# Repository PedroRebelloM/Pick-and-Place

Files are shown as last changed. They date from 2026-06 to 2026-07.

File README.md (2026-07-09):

# Máquina CNC Pick-and-Place (Separação Automática)

Uma máquina CNC (Controle Numérico Computadorizado) projetada para separar e organizar automaticamente parafusos e porcas de acordo com seus tipos, utilizando visão computacional e precisão robótica.

## 🎯 Visão Geral do Projeto

Este projeto visa desenvolver um sistema automatizado de *pick-and-place* (pegar e colocar) que:
- **Identifica** diferentes tipos de parafusos e porcas usando visão computacional.
- **Classifica** os fixadores por suas características (tamanho, tipo, formato).
- **Separa e Organiza** os componentes em recipientes ou compartimentos designados.
- **Otimiza** os movimentos de deslocamento e captura (eixos X e Y) para maior velocidade e precisão.

## 📋 Funcionalidades (Roadmap)

- [ ] Sistema de visão computacional para detecção e classificação de peças.
- [ ] Atuador magnético (Eletroímã controlado por Servo Motor) para captura precisa.
- [ ] Sistema de controle de movimento CNC (Arduino + CNC Shield).
- [ ] Separação e organização em tempo real.
- [ ] Regras de classificação personalizáveis.
- [ ] Interface de usuário (Dashboard) para monitoramento de estatísticas.

## 🏗️ Arquitetura do Sistema

### Componentes de Hardware
- Sistema de Movimento CNC:
  - 1 Arduino Uno
  - 1 CNC Shield V3.0
  - 3 Módulos de Driver A4988
  - 3 Motores NEMA 17
- Ferramenta de Captura:
  - Eletroímã
  - Servo Motor MG90S
  - Módulo Relé 
- Câmera para visão computacional.
- Recipientes de separação para os componentes classificados.

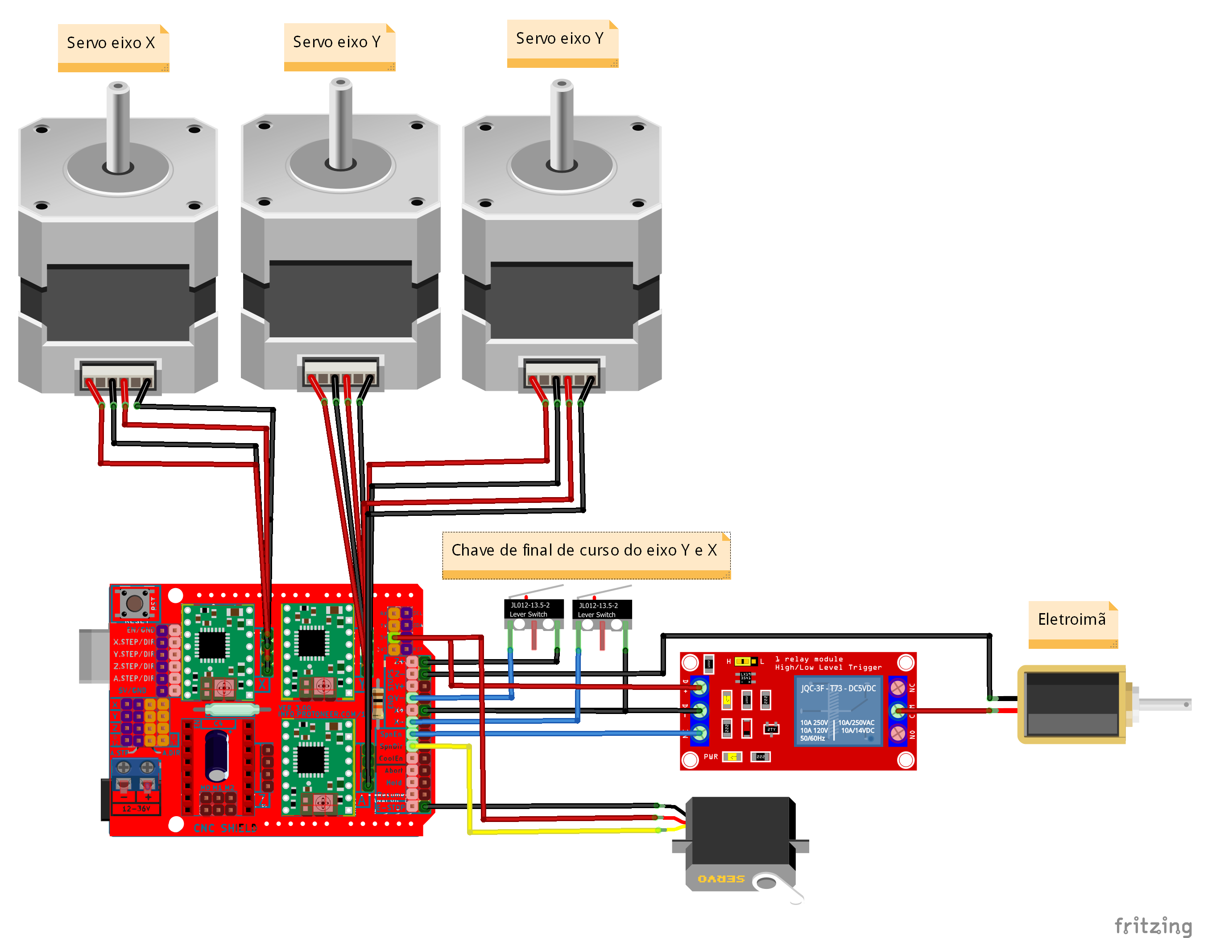
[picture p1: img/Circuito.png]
Circuito CNC


### Componentes de Software
- **Visão Computacional:** Algoritmo de detecção e classificação (Raspberry Pi / PC com Python e OpenCV).
- **Firmware de Controle de Movimento:** Lógica em C++ utilizando a [Biblioteca AccelStepper](https://github.com/adafruit/AccelStepper/blob/master/AccelStepper.h#L154) (Arduino).
- **Comunicação e Backend:** Processamento de dados em tempo real via porta Serial e servidor web (Python + flet).
- **Interface/Dashboard:** UI para monitoramento e configuração da máquina (Web/Flask).

---

## 🖨️ Peças 3D

Todos os componentes 3D personalizados foram projetados para otimizar a precisão, estabilidade e eficiência da máquina CNC. Abaixo estão os arquivos disponíveis:

| Peça | Descrição | Arquivo |
|---|---|---|
| **Cabeça CNC** | Componente principal de montagem e estrutura | [`cabeça_CNC.stl`](peças3D/cabeça_CNC.stl) |
| **Pinhão 17mm** | Pinhão para transmissão de movimento dos motores NEMA 17 | [`pinhao17mm.stl`](peças3D/pinhao17mm.stl) |
| **Cremalheira** | Cremalheira de transmissão linear para os eixos | [`cremalheira.stl`](peças3D/cremalheira.stl) |
| **Suporte Cremalheira** | Suporte estrutural para fixação da cremalheira | [`suporte_cremalheira.stl`](peças3D/suporte_cremalheira.stl) |
| **Suporte Câmera** | Suporte principal para montagem da câmera de visão | [`suporte_camera.stl`](peças3D/suporte_camera.stl) |
| **Suporte Câmera 2** | Suporte adicional/complementar para câmera | [`suporte_camera2.stl`](peças3D/suporte_camera2.stl) |
| **Calço Motor NEMA17** | Calço de alinhamento para os motores NEMA 17 | [`calço_motor_nema17.stl`](peças3D/calço_motor_nema17.stl) |
| **Fixador Motor** | Peça de fixação dos motores na estrutura | [`fixador_motor.stl`](peças3D/fixador_motor.stl) |

**Montagem das peças** :  [`montagem_cabeçaCNC.stl`](peças3D/montagem_cabeçaCNC.stl)

### 📥 Como Usar as Peças 3D

1. **Visualizar:** Acesse a pasta [`peças3D/`](peças3D) e abra os arquivos `.stl` em um visualizador 3D (ex: [Thingiverse Customizer](https://www.thingiverse.com/customizer), Fusion 360, FreeCAD).
2. **Imprimir:** Use um software de fatiamento (ex: Cura, PrusaSlicer) para preparar os arquivos `.stl` para sua impressora 3D.
3. **Modificar:** Os arquivos no formato `.x_t` podem ser editados em softwares de CAD como Fusion 360, SolidWorks ou FreeCAD.

---

## 📁 Estrutura de Diretórios

A estrutura atual do repositório é a seguinte:

```text
Pick-and-Place/
├── arduino/                 # Arquivos de firmware para o Arduino
│   ├── arduino.ino
│   └── funcoes.ino
├── img/                     # Imagens e materiais visuais do projeto
├── peças3D/                 # Arquivos 3D das peças da máquina
│   ├── cabeça_CNC.x_t
│   ├── pinhao17mm.stl
│   ├── cremalheira.stl
│   ├── suporte_cremalheira.stl
│   ├── suporte_camera.stl
│   ├── suporte_camera2.stl
│   ├── calço_motor_nema17.stl
│   └── fixador_motor.stl
├── src/                     # Código principal em Python
│   ├── binarizacao.py
│   ├── classe.py
│   ├── main.py
│   ├── video.py
│   └── images/              # Imagens usadas pelos scripts
├── requirements.txt         # Dependências do projeto
└── README.md                # Documentação do projeto
```

## 🚀 Como Começar

### Pré-requisitos
- [Arduino IDE](https://docs.arduino.cc/software/ide/) instalado para compilar o firmware.
- Python 3.12.10 instalado.
- Bibliotecas Python: opencv-python, pyserial, flet, numpy, scikit-learn.

### Instalação e Execução (Resumo)
- Faça o upload dos arquivos da pasta arduino/ para o seu Arduino Uno.
- Certifique-se de que a CNC Shield está devidamente alimentada.
- No terminal, navegue até a pasta backend/ e instale as dependências:
  - `pip install -r requirements.txt`
- Inicie o servidor flet: `flet run main.py`
- Acesse o Dashboard pelo seu navegador para controlar a máquina.

## 👤 Autores

- **Cris Guimarães**
- **Pedro Rebello M**
- **Pedro Ribeiro**

## 📸 Video

- https://youtu.be/jzBIY5suvXo

---

**Status**: Em desenvolvimento 🚧

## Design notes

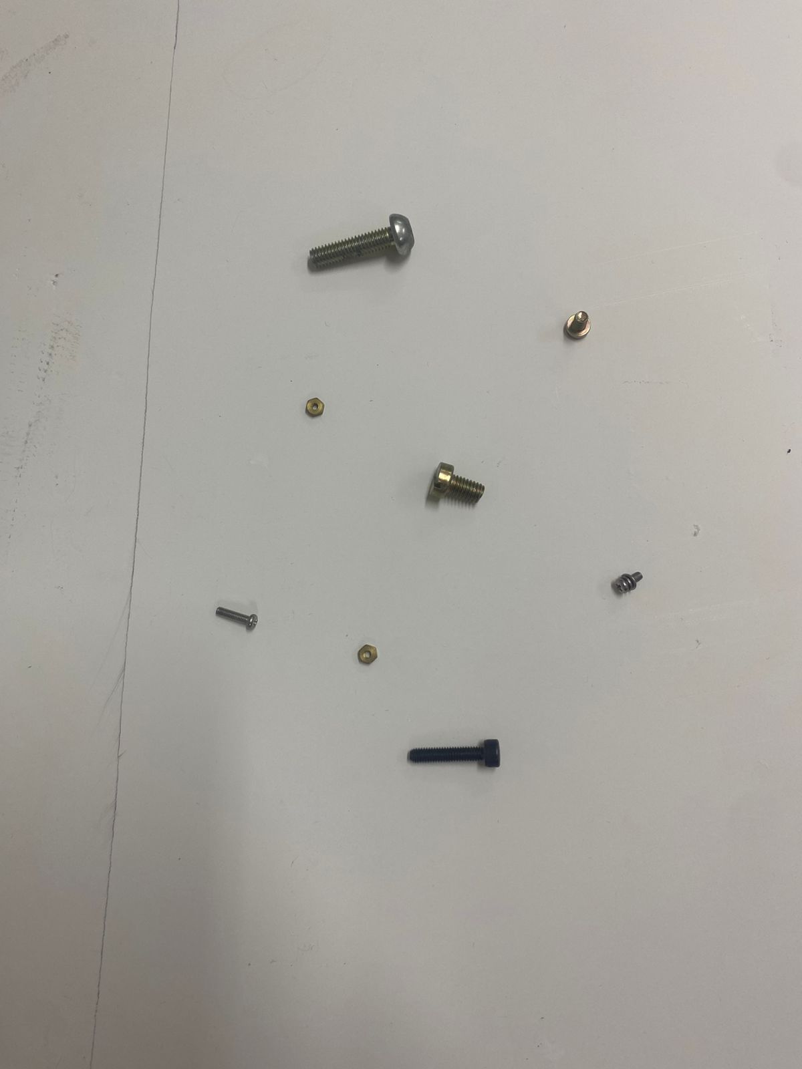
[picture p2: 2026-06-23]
src/images/sem_flash_longe.jpeg

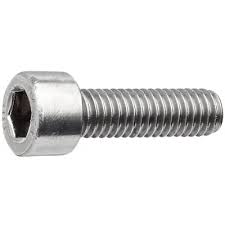
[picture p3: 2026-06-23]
src/images/parafuso.jpg

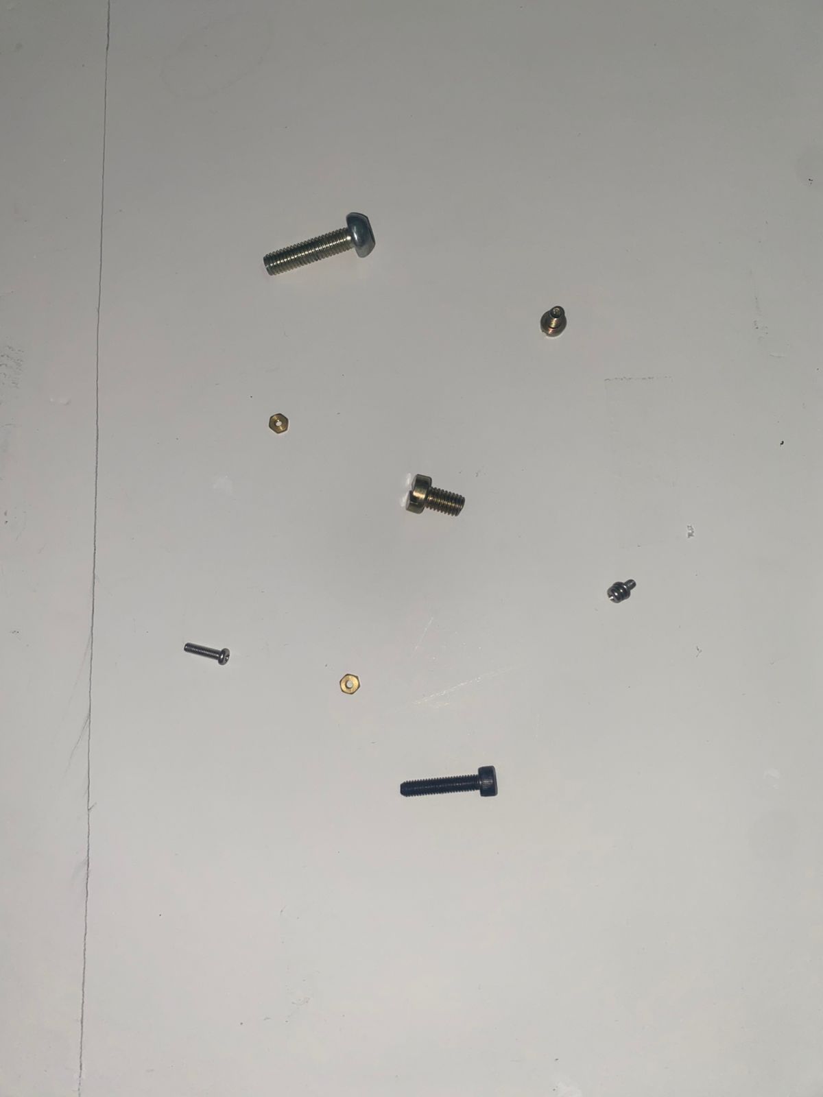
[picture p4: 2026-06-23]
src/images/com_flash_longe.jpeg

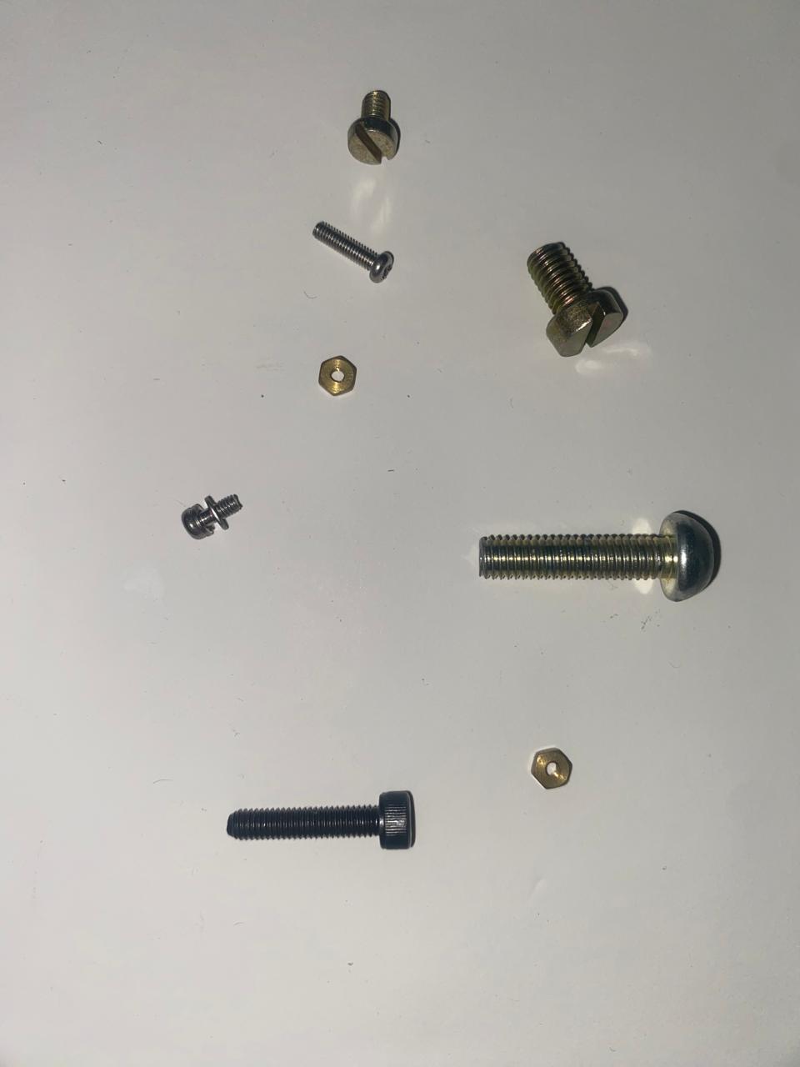
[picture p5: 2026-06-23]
src/images/com_flash_perto.jpeg

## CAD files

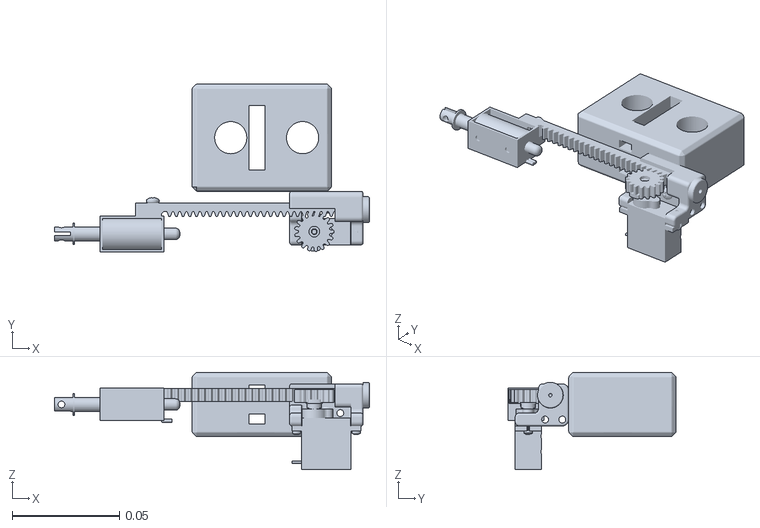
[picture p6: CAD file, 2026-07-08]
peças3D/montagem_cabeçaCNC.stl
0.147 x 0.0783 x 0.0454

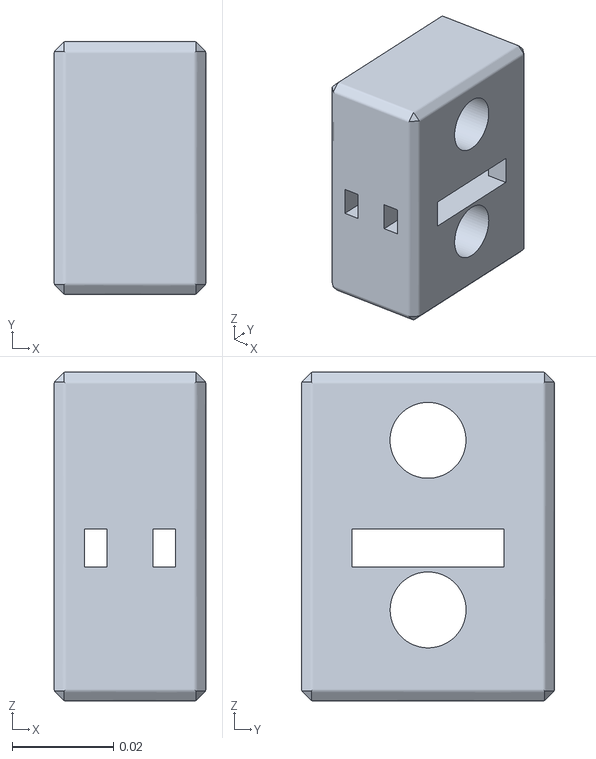
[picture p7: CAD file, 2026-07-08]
peças3D/cabeça_CNC.stl
0.03 x 0.05 x 0.065

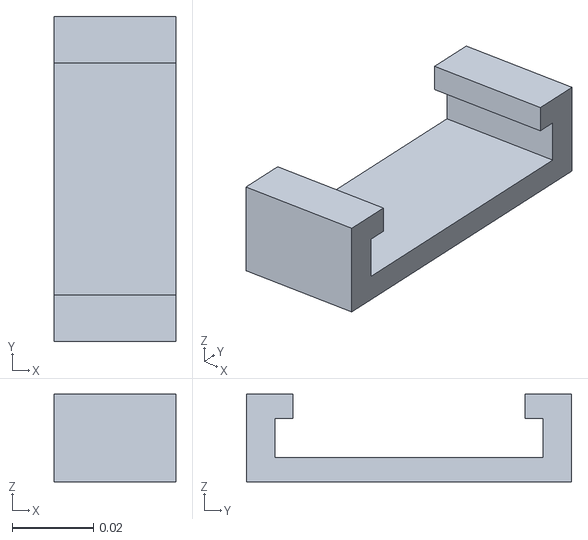
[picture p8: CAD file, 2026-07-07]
peças3D/suporte_camera2.stl
0.03 x 0.08 x 0.0216

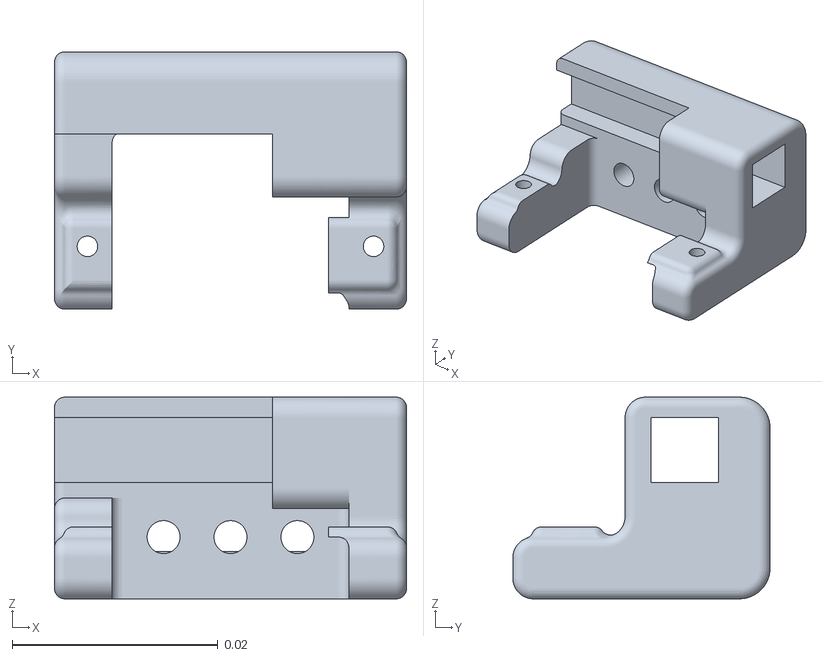
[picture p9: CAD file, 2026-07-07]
peças3D/suporte_cremalheira.stl
0.0342 x 0.025 x 0.0196

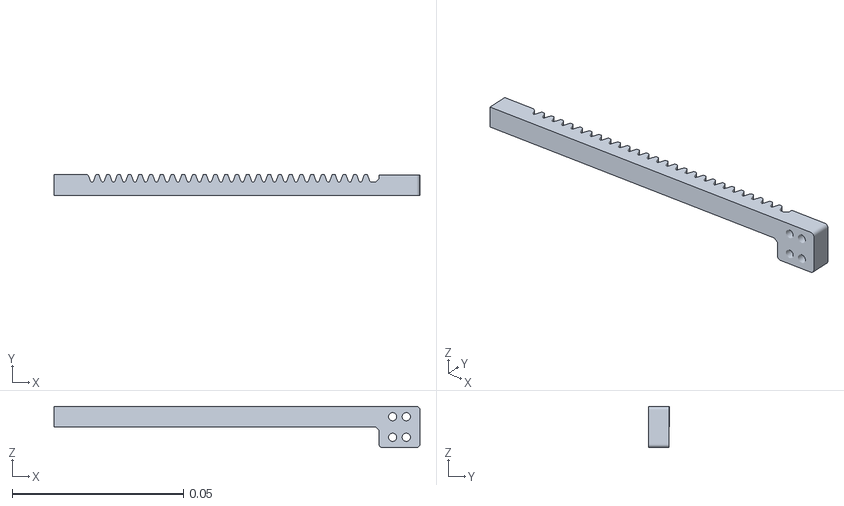
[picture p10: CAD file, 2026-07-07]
peças3D/cremalheira.stl
0.107 x 0.00625 x 0.012

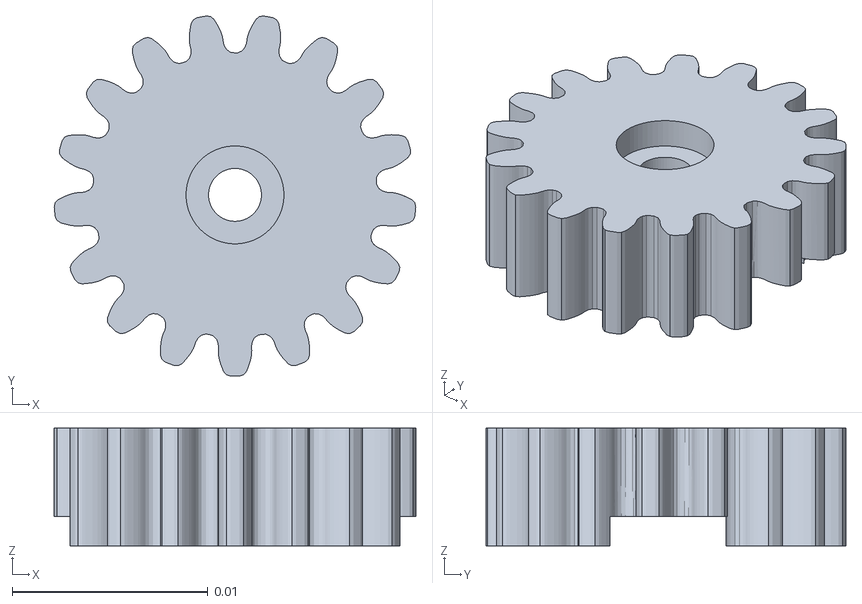
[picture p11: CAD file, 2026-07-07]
peças3D/pinhao17mm.stl
0.0185 x 0.0184 x 0.006

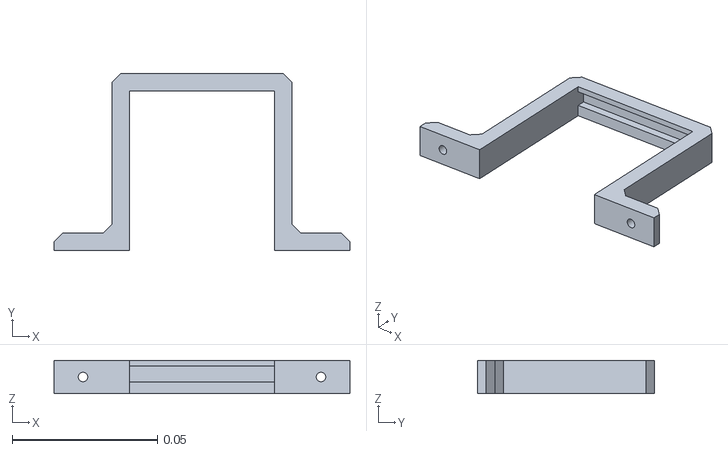
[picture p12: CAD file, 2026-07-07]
peças3D/fixador_motor.stl
0.102 x 0.061 x 0.0115

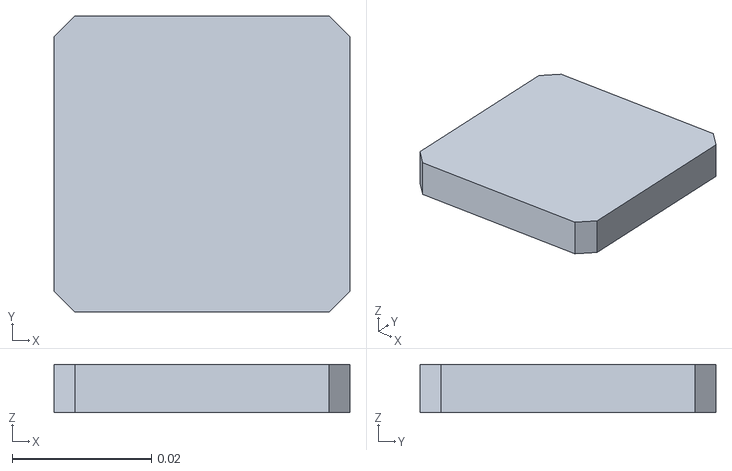
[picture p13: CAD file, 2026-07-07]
peças3D/calço_motor_nema17.stl
0.0425 x 0.0425 x 0.0069

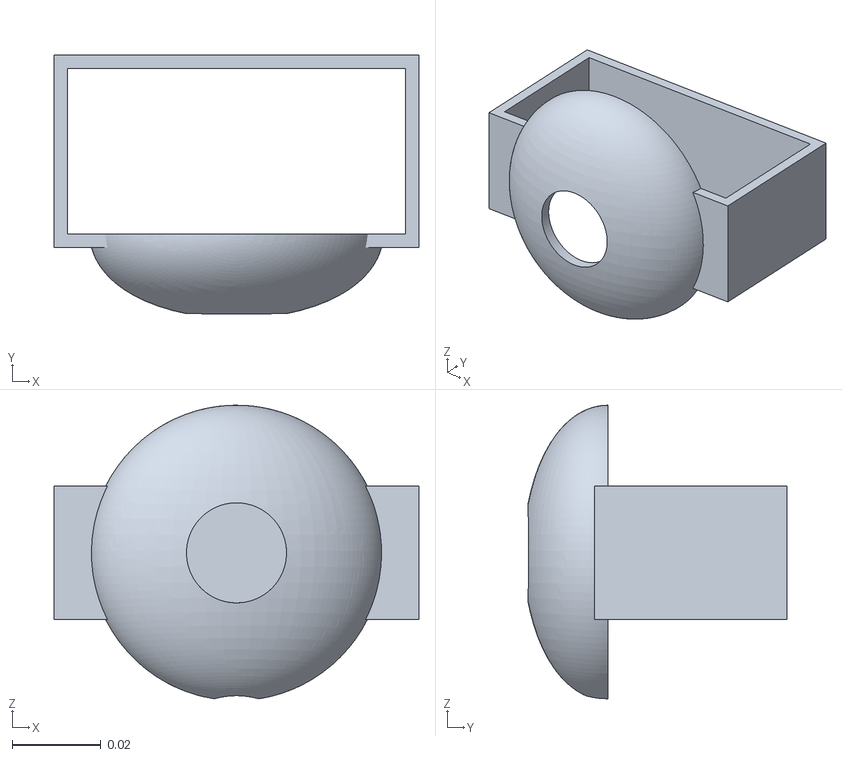
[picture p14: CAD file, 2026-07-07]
peças3D/suporte_camera.stl
0.0821 x 0.0581 x 0.066

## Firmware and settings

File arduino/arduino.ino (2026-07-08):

#include <AccelStepper.h>
#include <string.h>
#include <Servo.h>
#include <Adafruit_NeoPixel.h>

/*** Definição dos pinos padrão da CNC Shield V3.0 ***/
// Pino que liga/desliga a energia de todos os drivers
#define EN_PIN 8 

#define MOTOR_X_STEP 2
#define MOTOR_X_DIR 5

#define MOTOR_Y_STEP 3
#define MOTOR_Y_DIR 6

#define INICIO_CURSO_X 9
#define INICIO_CURSO_Y 11

#define RELE_IMA 12
#define MOTOR_IMA 13

#define SERVO_POS_INI 0

// Pino da fita de LED
#define PIN_LED 7 
// Quantidade de LEDs na fita/anel
#define NUM_LEDS 60

Adafruit_NeoPixel pixels(NUM_LEDS, PIN_LED, NEO_GRB + NEO_KHZ800);

Servo motor_ima;

int POS_X = 0;
int POS_Y = 0;

int JANELA_X = 1150;
int JANELA_Y = 1200;

float velocidade = 400;
float aceleracao = 300;

bool em_movimento = false;

float velo_homing = -400;

unsigned long contagem_tempo = 0;

/*** Instanciação dos motores usando a biblioteca ***/
// Primeiro parâmetro indica que será utilizado um driver exclusivo, no caso, o ... 
AccelStepper motor_x(1, MOTOR_X_STEP, MOTOR_X_DIR);
AccelStepper motor_y(1, MOTOR_Y_STEP, MOTOR_Y_DIR);


void setup() {
  Serial.begin(9600);

  // Habilita os drivers dos motores
  // ATENÇÃO: Se definir no código, não colocar jumper na placa
  pinMode(EN_PIN, OUTPUT);
  // Desabilita os drivers dos motores
  digitalWrite(EN_PIN, HIGH);

  // HIGH -> Chave aberta
  // LOW -> Chave fechada
  // Conexão no projeto -> Normalmente fechada
  pinMode(INICIO_CURSO_X, INPUT_PULLUP);
  pinMode(INICIO_CURSO_Y, INPUT_PULLUP);

  pinMode(RELE_IMA, OUTPUT);
  digitalWrite(RELE_IMA, HIGH);
  motor_ima.attach(MOTOR_IMA);
  motor_ima.write(SERVO_POS_INI);

  // Velocidade máxima no eixo x
  motor_x.setMaxSpeed(velocidade);
  // Aceleração no eixo x
  motor_x.setAcceleration(aceleracao);

  // Velocidade máxima no eixo y
  motor_y.setMaxSpeed(velocidade);
  // Aceleração no eixo y
  motor_y.setAcceleration(aceleracao);

  fita_led();

  homing ();

} // setup


void loop() {

  if (Serial.available() > 0) {
    // texto.trim(); // remove quebra de linha

    String comando = Serial.readStringUntil('\n');

    // MOVE X100 Y200
    // STOP
    // HOME
    // IMA DESCE
    // IMA SOBE
    // IMA LIGA
    // IMA DESLIGA
    // ESPALHA

    if (comando.startsWith("STOP") ) {
      motor_x.stop();
      motor_y.stop();
      digitalWrite(EN_PIN, HIGH);
    }
    else
    if(comando.startsWith("ESPALHA") ) {
      espalha_parafusos(velocidade, aceleracao);
    }
    if (comando.startsWith("MOVE")) {
      digitalWrite(EN_PIN, LOW);
      //Serial.print("Motores ligados");
      
      // Leitura da posição X e Y
      int index_X = comando.indexOf("X");
      int index_Y = comando.indexOf("Y");

      if (index_X != -1){
        POS_X = (comando.substring(index_X+1)).toInt();
      }
      if (index_Y != -1){
        POS_Y = (comando.substring(index_Y+1)).toInt();
      }

          // Define uma posição especifica de descolamento
      motor_x.moveTo(POS_X);
      motor_y.moveTo(POS_Y);

      // Avisa o sistema que um movimento acabou de começar
      em_movimento = true;
    } // MOVE
    else
    if (comando.startsWith("HOME")){
      homing ();
    }
    else
    if (comando.startsWith("IMA")){
      if (comando.substring(4) == "DESCE"){
        for (int angulo = 0; angulo <= 180; angulo++) {
          motor_ima.write(angulo);
          delay(15);
        }
        Serial.println("DESCI");
      } 
      else
      if (comando.substring(4) == "SOBE"){
        for (int angulo = 180; angulo >= 0; angulo--) {
          motor_ima.write(angulo);
          delay(15);
        }
        Serial.println("SUBI");
      }
      else
      if (comando.substring(4) == "LIGA"){
        digitalWrite(RELE_IMA, LOW);
        Serial.println("LIGUEI");
      }
      else
      if (comando.substring(4) == "DESLIGA"){
        digitalWrite(RELE_IMA, HIGH);
        Serial.println("DESLIGUEI");
      }
    }
    else{
      Serial.println("Comando inválido!");  
    }

    //Serial.print("Posições X e Y: ");
    //Serial.print(POS_X);
    //Serial.print(" ");
    //Serial.println(POS_Y);
  
  } // leitura serial

  // Verifica se o motor x e o motor y chegarram a posição definada anteriormente
  // Se verdadeiro, desliga a alimentação do motores
  if (em_movimento && motor_x.distanceToGo() == 0 && motor_y.distanceToGo() == 0){
    digitalWrite(EN_PIN, HIGH);

    Serial.println("CHEGUEI");
    em_movimento = false;
  } 

  motor_x.run();
  motor_y.run();

  // Impressão de teste
  if (millis() > contagem_tempo + 1000) {
    // Retorna a velocidade do motor em dado instante
    //float vel_x = motor_x.speed();
    //Serial.print("Velocidade x: ");
    //Serial.println(vel_x);
    
    //float vel_y = motor_y.speed();
    //Serial.print("Velocidade y: ");
    //Serial.println(vel_y);

    contagem_tempo = millis();
  } // millis

} // loop

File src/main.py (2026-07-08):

import asyncio
import time
import flet as ft
import serial
import serial.tools.list_ports
from classe import ScrewDetector

try:
    arduino = serial.Serial('COM9', 9600, timeout=1)
except Exception as e:
    print(f"Arduino não conectado! Erro detalhado: {e}")
    arduino = None

async def main(page: ft.Page):
    # configura propriedades basicas da janela
    page.title = "ENG4033 - Classificador de Parafusos"
    page.horizontal_alignment = ft.CrossAxisAlignment.CENTER
    page.theme_mode = ft.ThemeMode.DARK
    page.padding = 20

    # cria um pixel invisivel temporario para evitar erro de imagem vazia ao carregar
    pixelFicticio = "data:image/png;base64,iVBORw0KGgoAAAANSUhEUgAAAAEAAAABCAQAAAC1HAwCAAAAC0lEQVR42mNkYAAAAAYAAjCB0C8AAAAASUVORK5CYII="
    videoFrame = ft.Image(src=pixelFicticio, fit="contain", gapless_playback=True)
    
    # texto informativo de status na base da tela
    statusText = ft.Text(
        "Inicializando câmera", 
        size=16, 
        weight=ft.FontWeight.BOLD,
        color=ft.Colors.GREEN_400
    )

    detector = ScrewDetector(camera_id=1)
    
    # atualiza o status dependendo se o hardware foi localizado
    if detector.is_opened():
        statusText.value = "Sistema pronto"
    else:
        statusText.value = "Erro"
        statusText.color = ft.Colors.RED_400

    # guarda os dados da operacao
    estado = {
        "running": False,
        "comecar_time": None,
        "tempo_parado": 0.0,
        "movendo": False, 
        "magnetizado": False,
        "zm_atual": (0, 0, 540, 1080),
        "ignorar_ate": 0.0,
        "fase_movimento": "livre"
    }

    time_text = ft.Text("Tempo: 00:00:00", size=20, weight=ft.FontWeight.BOLD, color=ft.Colors.YELLOW_400)

    # funcao executada ao clicar no botao comecar
    def btn_comecar_click(e):
        if not estado["running"]:
            estado["running"] = True
            estado["comecar_time"] = time.time()
            statusText.value = "Sistema operando"
            statusText.color = ft.Colors.GREEN_400
            statusText.update()

    def btn_descer_click(e):
        if arduino is not None:
            arduino.write("IMA DESCE\n".encode("utf-8"))

    def btn_subir_click(e):
        if arduino is not None:
            arduino.write("IMA SOBE\n".encode("utf-8"))

    def btn_magnetizar_click(e):
        if arduino is not None:
            arduino.write("IMA LIGA\n".encode("utf-8"))
            estado["magnetizado"] = True
        else:
            print("Erro magnetizar")

    def btn_desmagnetizar_click(e):
        if arduino is not None:
            arduino.write("IMA DESLIGA\n".encode("utf-8"))
            estado["magnetizado"] = False
        else:
            print("Erro desmagnetizar")
            
            
    # funcao executada ao clicar no botao pausar
    def btn_pause_click(e):
        if estado["running"]:
            estado["running"] = False
            estado["tempo_parado"] += time.time() - estado["comecar_time"]
            statusText.value = "Sistema PAUSADO"
            statusText.color = ft.Colors.ORANGE_400
            statusText.update()
            
            if arduino is not None:
                arduino.write("STOP\n".encode("utf-8"))

    def btn_home_click(e):
        if arduino is not None:
            estado["movendo"] = True
            estado["fase_movimento"] = "indo_home"
            arduino.write(b'HOME\n')
            print("Enviado: HOME")

        else:
            print("Erro home")

    def btn_mover_click(e):
        if arduino is not None:
            x_val = input_x.value if input_x.value else "0"
            y_val = input_y.value if input_y.value else "0"
            comando = f"MOVE X{x_val} Y{y_val}\n"
            
            print(f"Python enviou: {comando.strip()}")
            arduino.write(comando.encode("utf-8"))
        else:
            print("Erro mover_click")

    def btn_restaurar_padroes(e):
        detector.restaurar_padroes()
        input_h_min.value = str(detector.default_limite_inf[0])
        input_s_min.value = str(detector.default_limite_inf[1])
        input_v_min.value = str(detector.default_limite_inf[2])
        input_h_max.value = str(detector.default_limite_sup[0])
        input_s_max.value = str(detector.default_limite_sup[1])
        input_v_max.value = str(detector.default_limite_sup[2])
        
        statusText.value = "Padrões Restaurados"
        statusText.color = ft.Colors.BLUE_400
        statusText.update()
        page.update()

    def btn_espalhar_click(e):
        if arduino is not None:
            # Envia o comando "ESPALHA" pela porta serial
            arduino.write("ESPALHA\n".encode("utf-8"))
            print("Enviado: ESPALHA")
            estado["movendo"] = True
            # Como a máquina vai demorar, você pode opcionalmente criar um estado novo "espalhando" ou só usar "livre"
            estado["fase_movimento"] = "espalhando"
            statusText.value = "Espalhando Parafusos"
            statusText.color = ft.Colors.PURPLE_400
            statusText.update()

    # desenha os botoes na interface
    btn_comecar = ft.Button("Começar", icon="play_arrow", on_click=btn_comecar_click, bgcolor=ft.Colors.GREEN_700, color=ft.Colors.WHITE)
    btn_pause = ft.Button("Pausar", icon="pause", on_click=btn_pause_click, bgcolor=ft.Colors.ORANGE_700, color=ft.Colors.WHITE)
    
    btn_descer = ft.Button("Descer", icon="arrow_downward", on_click=btn_descer_click, bgcolor=ft.Colors.BLUE_700, color=ft.Colors.WHITE)
    btn_subir = ft.Button("Subir", icon="arrow_upward", on_click=btn_subir_click, bgcolor=ft.Colors.PURPLE_700, color=ft.Colors.WHITE)
    
    btn_magnetizar = ft.Button("Ímã ON", icon="bolt", on_click=btn_magnetizar_click, bgcolor=ft.Colors.RED_700, color=ft.Colors.WHITE)
    btn_desmagnetizar = ft.Button("Ímã OFF", icon="power_off", on_click=btn_desmagnetizar_click, bgcolor=ft.Colors.BROWN_700, color=ft.Colors.WHITE)

    btn_home = ft.Button("Homing", icon="home", on_click=btn_home_click, bgcolor=ft.Colors.BROWN_700, color=ft.Colors.WHITE)
    btn_restaurar = ft.Button("Restaurar Limites", icon="restore", on_click=btn_restaurar_padroes, bgcolor=ft.Colors.GREY_700, color=ft.Colors.WHITE)

    btn_espalhar = ft.Button("Espalhar", icon="", on_click=btn_espalhar_click, bgcolor=ft.Colors.GREY_700, color=ft.Colors.WHITE)

    # campos de texto para movimentacao manual
    input_x = ft.TextField(label="X", width=80, height=40, text_size=14, keyboard_type=ft.KeyboardType.NUMBER)
    input_y = ft.TextField(label="Y", width=80, height=40, text_size=14, keyboard_type=ft.KeyboardType.NUMBER)
    btn_mover = ft.Button("Mover", icon="open_with", on_click=btn_mover_click, bgcolor=ft.Colors.TEAL_700, color=ft.Colors.WHITE)
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

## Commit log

2026-06-26 Inserção das funções para mexer na CNC via Python.
2026-06-29 Descomentando comando arduino
2026-06-30 Implementando funçao de espalhar parafusos
    Add function to spread screws with servo control
2026-06-30 Implementando levantamneto de servo apos espalhar
    Added servo control to lift the servo to a starting position.
2026-07-07 Adiciona seção de Peças 3D com visualização dos componentes
2026-07-07 Change CNC head file format and add assembly instructions
    Updated file references for CNC components and added assembly zip file.
2026-07-07 Change assembly file reference from ZIP to STL
    Updated the file reference for assembly instructions from ZIP to STL format.
2026-07-08 Refactor espalha_parafusos and homing functions
2026-07-08 Opção de ajuste da máscara via interface
